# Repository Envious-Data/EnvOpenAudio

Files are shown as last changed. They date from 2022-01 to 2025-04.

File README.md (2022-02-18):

# EnvOpenAudio
 An open source headphone/PC speaker project utilizing the RP2040, UDA1334A and TPA2016

## Why
I like the idea of using the RP2040 for as many things as possible and since I made my own type-c version of the pico and my phone doesnt have a 3.5mm jack its a nice little bonus... I was also thinking I could use a Tiny2040 since its even smaller than a Pro Micro style board and also has all 4 Analogue GPIOs.

## I will need help
Im not a programmer, the most I can do is scripting in bash and python, that said I need someone who can do C stuff, although there is an example for using the Rpi pico as a I2S USB Sound Card it doesnt fully function, it functions enough to use for a while but mute doesnt work and eventually USB will die off for some reason.
https://github.com/raspberrypi/pico-playground/tree/master/apps/usb_sound_card

## Contributions
Feel free to make a PR if you want to provide your own 3d modeled housings for 3d printable speakers housings or headphone cups, Ill obviously be modeling my own but its always nice to see how people approach things.

## to do list (In no particular order)
- [x] Make Functional Concept
- [ ] Firmware
- [ ] PC Speaker Housinds
- [ ] Headphone cups and band
- [ ] Custom smaller PCBs of I2S Decoder and amp.
- [x] ~~Meow at wall for 3 hours~~

## Currently working on (as of last updating this)
- 3d printed housing for speakers, small desktop style pc speakers

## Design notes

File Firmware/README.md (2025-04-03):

# I NEED HELP!

So I am not able to do much more than basic scripting and I'd love if someone could help out by providing a simple firmware for the RP2040 for this project

This example does almost everything I need except it seems to exhibit some bugs so I will be using this to test and work on this project but yeah, need someone to do the firmware bits.
https://github.com/raspberrypi/pico-playground/tree/master/apps/usb_sound_card

## tl:dr:
need firmware for rp2040 to make it USB I2S DAC.

### bonus features
- a basic EQ to adjust sound a bit incase you use different kinds of speakers to me.

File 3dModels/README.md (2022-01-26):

# EnvOpenAudio

Everything for this project Ill intend to be 3d printed, I'd like for everything to be as accessible as possible as usual.

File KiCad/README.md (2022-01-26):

# EnvOpenAudio

These board schematics are from adafruit, Ive imported them into KiCad and swapped the footprints to KiCad version, I will be attempting to make these boards smaller as well as removing some stuff I wont use but the good thing about this is if you want you can build this project out of such parts you can buy from adafruit or equivilent shops minus the 3d printed housings.

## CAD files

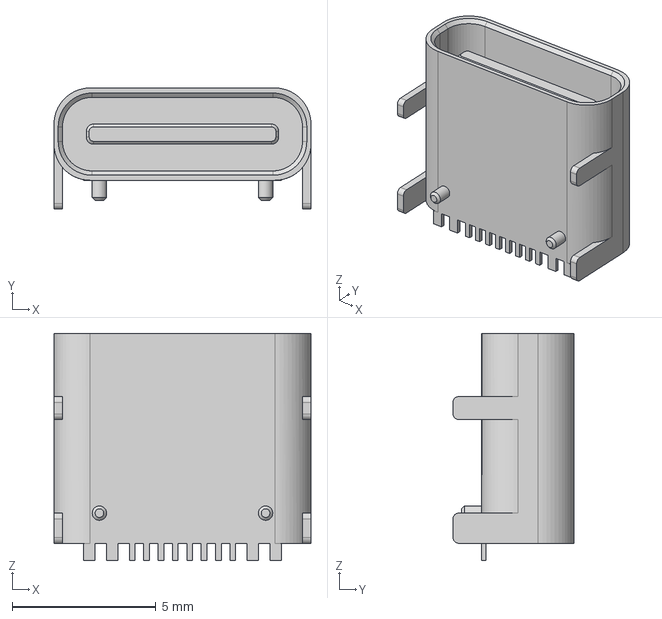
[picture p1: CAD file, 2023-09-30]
KiCad/EnvOpenAudio-RP2040/Resources/HRO TYPE-C-31-M-12.step
8.94 x 4.21 x 7.90 mm

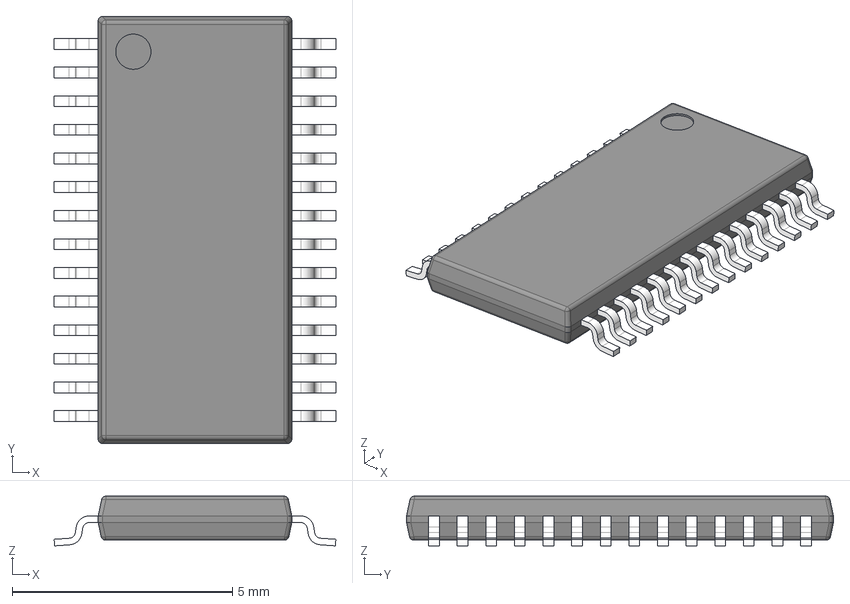
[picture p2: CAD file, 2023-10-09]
KiCad/EnvOpenAudio-RP2040/Resources/PCM3060PWR/PCM3060PWR.stp
6.40 x 9.70 x 1.13 mm
BODY-TSSOP
LEAD-TSSOP x 28
PIN1

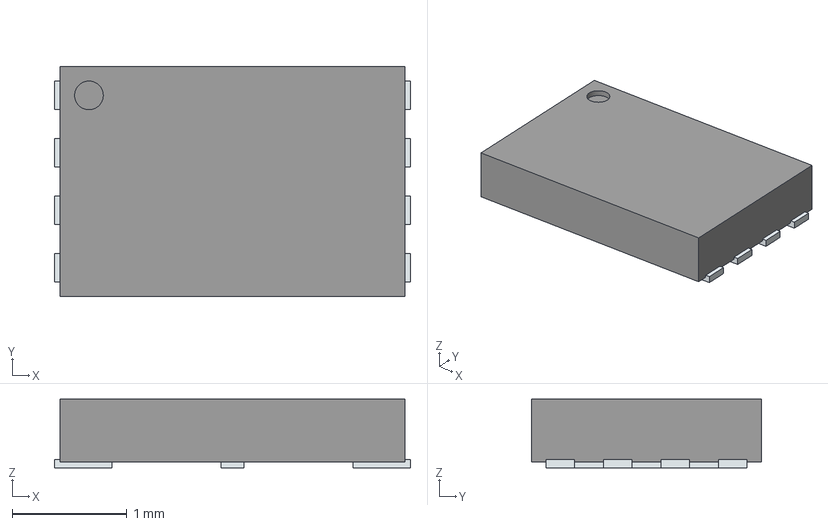
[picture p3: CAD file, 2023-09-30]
KiCad/EnvOpenAudio-RP2040/Resources/W25Q16JVUXIQ_TR.stp
3.10 x 2.00 x 0.6 mm
ThermalPin
PinsArrayLR

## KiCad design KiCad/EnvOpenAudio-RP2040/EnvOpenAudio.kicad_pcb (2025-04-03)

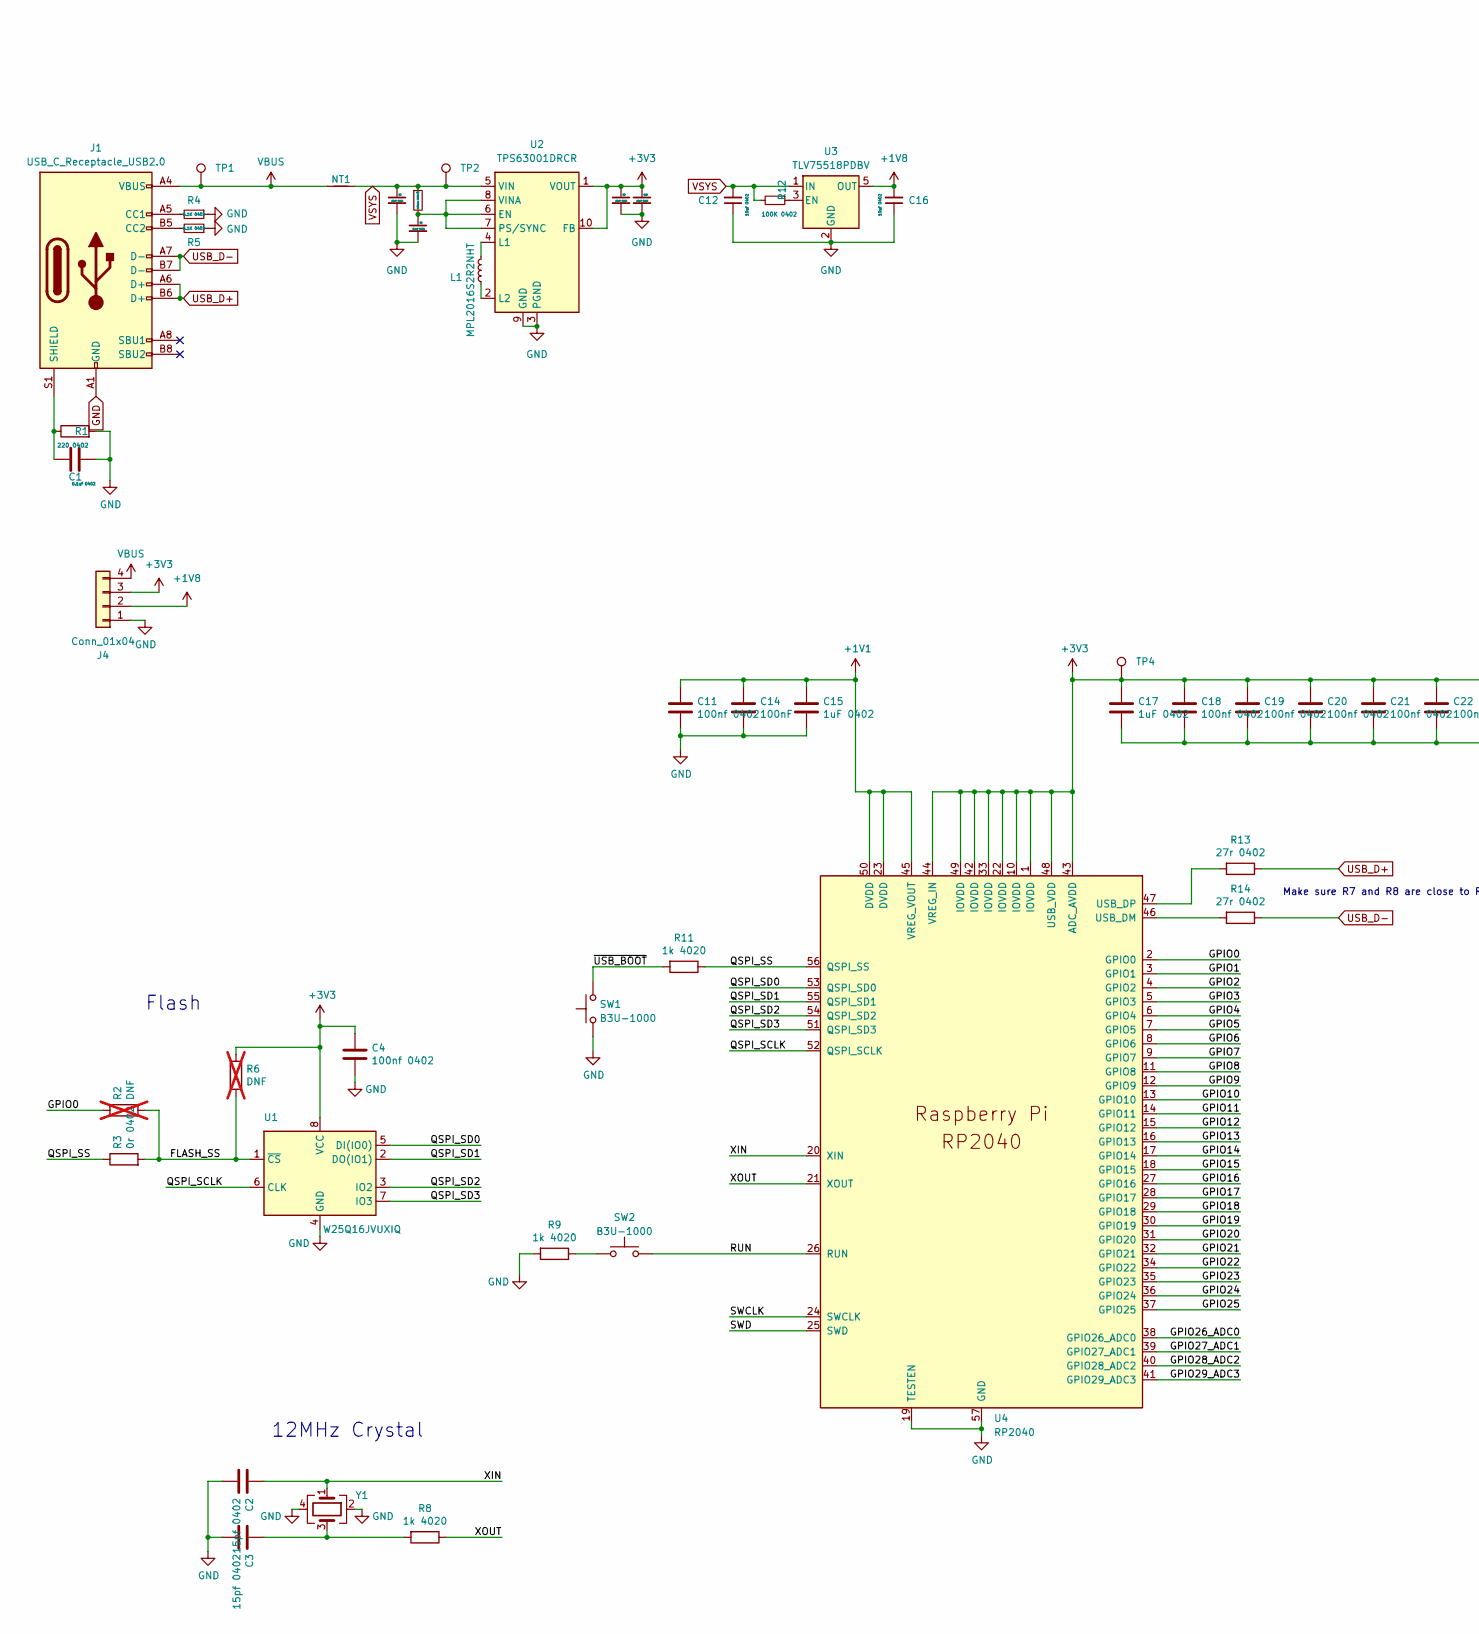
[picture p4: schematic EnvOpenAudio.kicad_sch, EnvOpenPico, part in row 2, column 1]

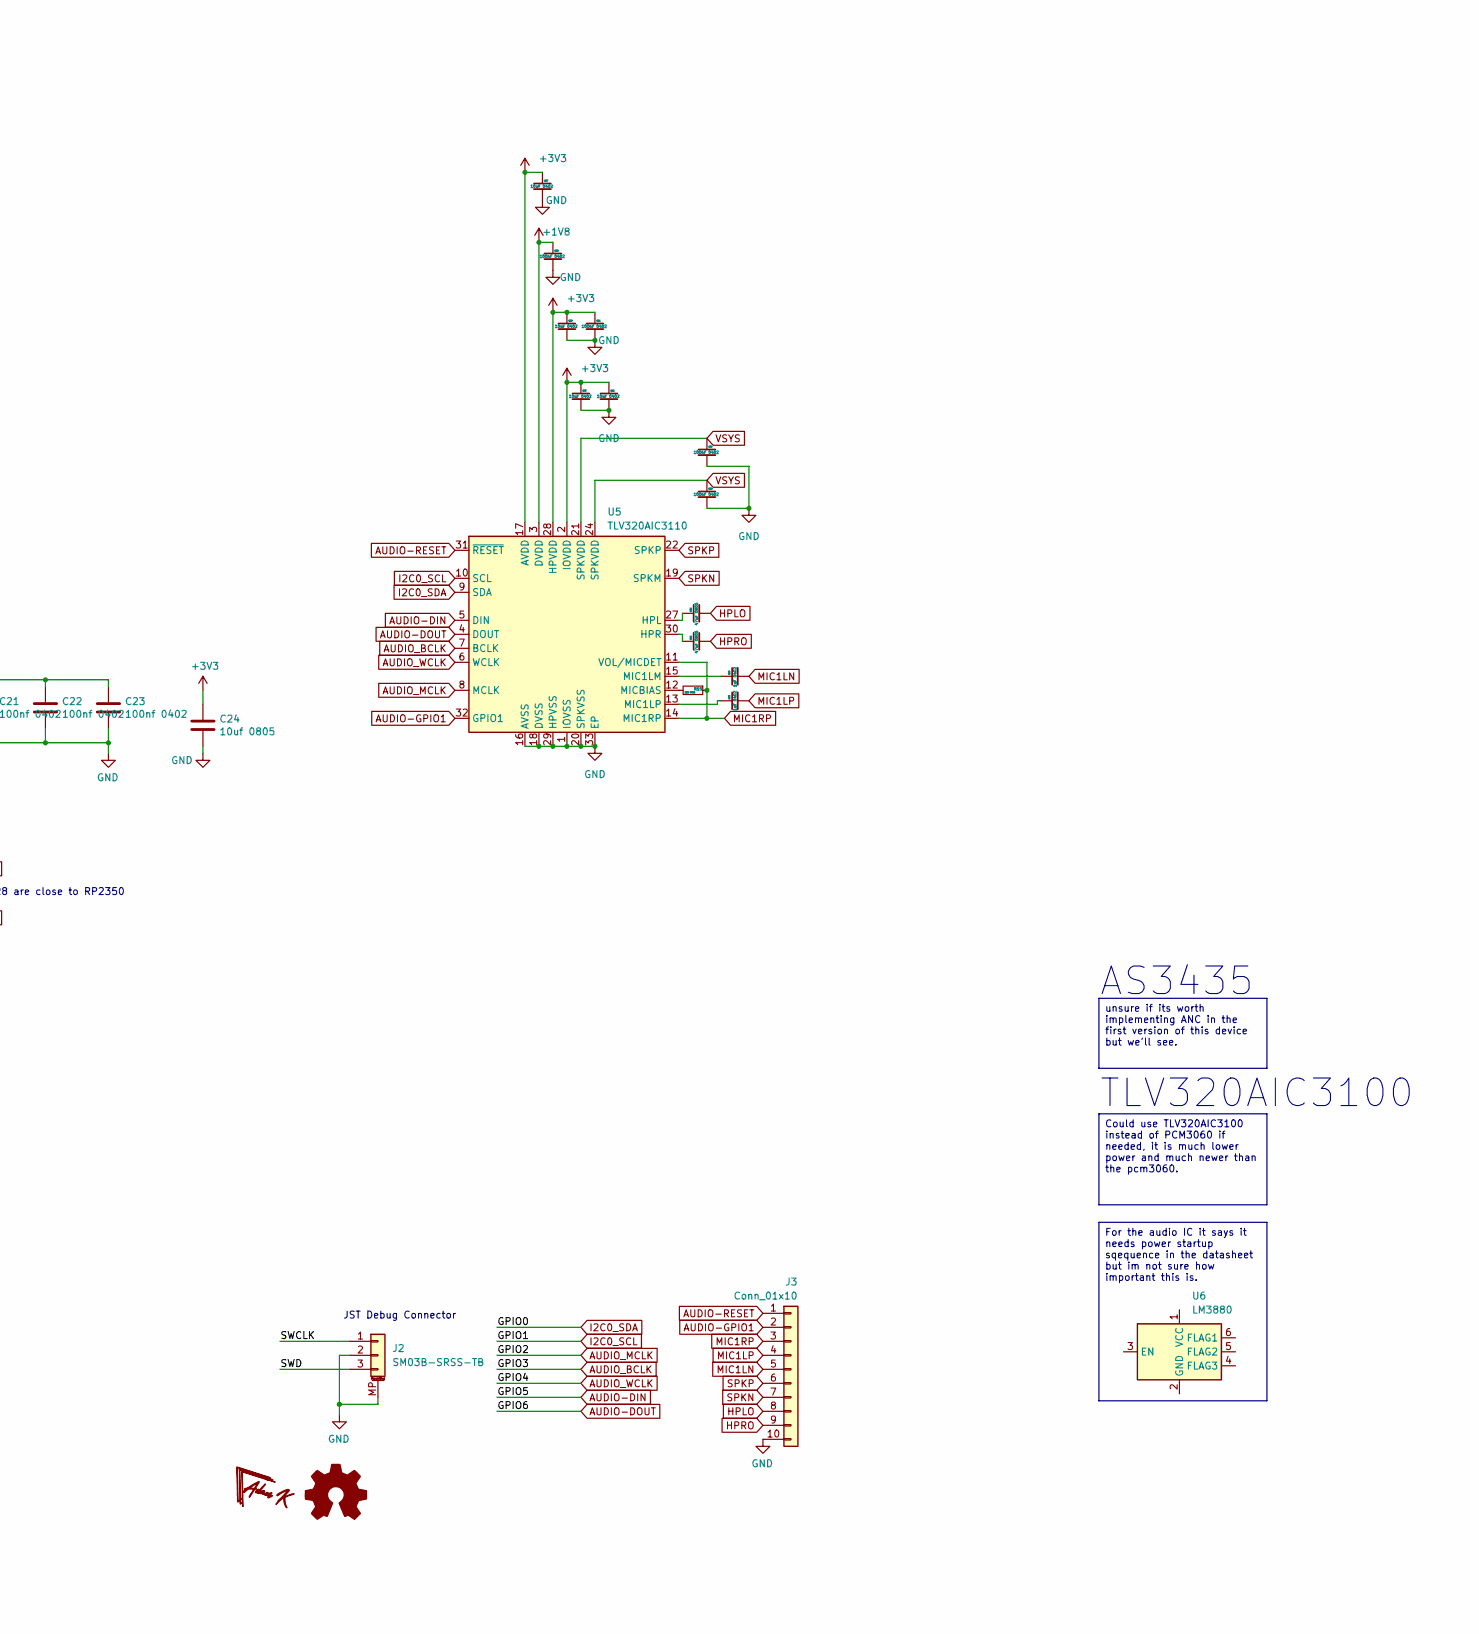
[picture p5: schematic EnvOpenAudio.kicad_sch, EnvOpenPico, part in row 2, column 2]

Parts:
C1: 0.1uf 0402; C_0402_1005Metric
C2, C3: 15pf 0402; C_0402_1005Metric
C4, C11, C18, C19, C20, C21, C22, C23: 100nf 0402; C_0402_1005Metric
C5, C9, C10, C27, C28, C30, C32: 10uF 0402; C_0402_1005Metric
C6: 0.1uF 0402; C_0402_1005Metric
C12, C16: 10uf 0402; C_0402_1005Metric
C14: 100nF; C_0402_1005Metric
C15, C17, C39, C40: 1uF 0402; C_0402_1005Metric
C24: 10uf 0805; C_0805_2012Metric
C29, C31, C37, C38: 100nF 0402; C_0402_1005Metric
C35, C36: 47uF 0805; C_0805_2012Metric
J1: USB_C_Receptacle_USB2.0; USB_C_Receptacle_HRO_TYPE-C-31-M-12
J2: SM03B-SRSS-TB; JST_SH_SM03B-SRSS-TB_1x03-1MP_P1.00mm_Horizontal
J3: Conn_01x10; PinHeader_2x05_P2.54mm_Vertical
J4: Conn_01x04; PinHeader_1x04_P2.54mm_Vertical
L1: MPL2016S2R2NHT; L_0805_2012Metric
NT1: NetTie_2; NetTie-2_SMD_Pad2.0mm
R1: 220 0402; R_0402_1005Metric
R2, R6: DNF; R_0402_1005Metric; not fitted
R3: 0r 0402; R_0402_1005Metric
R4, R5: 5.1K 0402; R_0402_1005Metric
R7: 100ohm 0402; R_0402_1005Metric
R8, R9, R11: 1k 4020; R_0402_1005Metric
R12: 100K 0402; R_0402_1005Metric
R13, R14: 27r 0402; R_0402_1005Metric
R15: 22K 0402; R_0402_1005Metric
SW1, SW2: B3U-1000; SW_SPST_B3U-1000P-B
TP1, TP2, TP3, TP4: TestPoint; TestPoint_Pad_D1.0mm
U1: W25Q16JVUXIQ; SON-8-1EP_3x2mm_P0.5mm_EP1.4x1.6mm
U2: TPS63001DRCR; Texas_DRC0010J_ThermalVias
U3: TLV75518PDBV; SOT-23-5
U4: RP2040; RP2040-QFN-56
U5: TLV320AIC3110; VQFN-32-1EP_5x5mm_P0.5mm_EP3.15x3.15mm_ThermalVias
U6: LM3880; SOT-23-6
Y1: 12Mhz 2520 18pF; Crystal_SMD_2520-4Pin_2.5x2.0mm

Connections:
+1V1: C11.1, C14.1, C15.1, U4.23 (DVDD), U4.45 (VREG_VOUT), U4.50 (DVDD)
+1V8: C16.2, C29.1, J4.2, U3.5 (OUT), U5.3 (DVDD)
+3V3: C4.1, C9.1, C10.1, C17.1, C18.1, C19.1, C20.1, C21.1, C22.1, C23.1, C24.1, C27.1, C28.1, C30.1, C31.1, C32.1, J4.3, R6.1, TP4.1, U1.8 (VCC), U2.1 (VOUT), U2.10 (FB), U4.1 (IOVDD), U4.10 (IOVDD), U4.22 (IOVDD), U4.33 (IOVDD), U4.42 (IOVDD), U4.43 (ADC_AVDD), U4.44 (VREG_IN), U4.48 (USB_VDD), U4.49 (IOVDD), U5.2 (IOVDD), U5.17 (AVDD), U5.28 (HPVDD)
/FLASH_SS: R2.2, R3.2, R6.2, U1.1 (~CS)
/GPIO7: U4.9 (GPIO7)
/GPIO8: U4.11 (GPIO8)
/GPIO9: U4.12 (GPIO9)
/GPIO10: U4.13 (GPIO10)
/GPIO11: U4.14 (GPIO11)
/GPIO12: U4.15 (GPIO12)
/GPIO13: U4.16 (GPIO13)
/GPIO14: U4.17 (GPIO14)
/GPIO15: U4.18 (GPIO15)
/GPIO16: U4.27 (GPIO16)
/GPIO17: U4.28 (GPIO17)
/GPIO18: U4.29 (GPIO18)
/GPIO19: U4.30 (GPIO19)
/GPIO20: U4.31 (GPIO20)
/GPIO21: U4.32 (GPIO21)
/GPIO22: U4.34 (GPIO22)
/GPIO23: U4.35 (GPIO23)
/GPIO24: U4.36 (GPIO24)
/GPIO25: U4.37 (GPIO25)
/GPIO26_ADC0: U4.38 (GPIO26_ADC0)
/GPIO27_ADC1: U4.39 (GPIO27_ADC1)
/GPIO28_ADC2: U4.40 (GPIO28_ADC2)
/GPIO29_ADC3: U4.41 (GPIO29_ADC3)
/QSPI_SCLK: U1.6 (CLK), U4.52 (QSPI_SCLK)
/QSPI_SD0: U1.5 (DI(IO0)), U4.53 (QSPI_SD0)
/QSPI_SD1: U1.2 (DO(IO1)), U4.55 (QSPI_SD1)
/QSPI_SD2: U1.3 (IO2), U4.54 (QSPI_SD2)
/QSPI_SD3: U1.7 (IO3), U4.51 (QSPI_SD3)
/QSPI_SS: R3.1, R11.1, U4.56 (QSPI_SS)
/RUN: SW2.2, U4.26 (RUN)
/SWCLK: J2.1, U4.24 (SWCLK)
/SWD: J2.3, U4.25 (SWD)
/XIN: C2.1, U4.20 (XIN), Y1.1
/XOUT: R8.1, U4.21 (XOUT)
/~USB_BOOT: R11.2, SW1.2
AUDIO-DIN: U4.7 (GPIO5), U5.5 (DIN)
AUDIO-DOUT: U4.8 (GPIO6), U5.4 (DOUT)
AUDIO-GPIO1: J3.2, U5.32 (GPIO1)
AUDIO-RESET: J3.1, U5.31 (~RESET)
AUDIO_BCLK: U4.5 (GPIO3), U5.7 (BCLK)
AUDIO_MCLK: U4.4 (GPIO2), U5.8 (MCLK)
AUDIO_WCLK: U4.6 (GPIO4), U5.6 (WCLK)
GND: C1.1, C2.2, C3.2, C4.2, C5.2, C6.2, C9.2, C10.2, C11.2, C12.1, C14.2, C15.2, C16.1, C17.2, C18.2, C19.2, C20.2, C21.2, C22.2, C23.2, C24.2, C27.2, C28.2, C29.2, C30.2, C31.2, C32.2, C37.2, C38.2, J1.A1 (GND), J1.A12 (GND), J1.B1 (GND), J1.B12 (GND), J2.2, J2.MP (MountPin), J3.10, J4.1, R1.2, R4.1, R5.1, R9.2, SW1.1, U1.4 (GND), U2.3 (PGND), U2.9 (GND), U2.11 (PGND), U3.2 (GND), U4.19 (TESTEN), U4.57 (GND), U5.1 (IOVSS), U5.16 (AVSS), U5.18 (DVSS), U5.20 (SPKVSS), U5.25 (SPKVSS), U5.29 (HPVSS), U5.33 (EP), Y1.2, Y1.4
HPLO: C35.2, J3.8
HPRO: C36.2, J3.9
I2C0_SCL: U4.3 (GPIO1), U5.10 (SCL)
I2C0_SDA: R2.1, U4.2 (GPIO0), U5.9 (SDA)
MIC1LN: C39.2, J3.5
MIC1LP: C40.2, J3.4
MIC1RP: J3.3, R15.1, U5.11 (VOL/MICDET), U5.14 (MIC1RP)
unnamed: C3.1, R8.2, Y1.3
unnamed: J1.A5 (CC1), R4.2
unnamed: J1.B5 (CC2), R5.2
unnamed: C1.2, J1.S1 (SHIELD), R1.1
unnamed: R9.1, SW2.1
unnamed: C6.1, R7.2, U2.6 (EN), U2.7 (PS/SYNC), U2.8 (VINA)
unnamed: L1.1, U2.4 (L1)
unnamed: L1.2, U2.2 (L2)
unnamed: R12.1, U3.3 (EN)
unnamed: R14.2, U4.46 (USB_DM)
unnamed: R13.2, U4.47 (USB_DP)
unnamed: C35.1, U5.27 (HPL)
unnamed: C36.1, U5.30 (HPR)
unnamed: C39.1, U5.15 (MIC1LM)
unnamed: C40.1, U5.13 (MIC1LP)
unnamed: R15.2, U5.12 (MICBIAS)
SPKN: J3.7, U5.19 (SPKM), U5.23 (SPKM)
SPKP: J3.6, U5.22 (SPKP), U5.26 (SPKP)
USB_D+: J1.A6 (D+), J1.B6 (D+), R13.1
USB_D-: J1.A7 (D-), J1.B7 (D-), R14.1
VBUS: J1.A4 (VBUS), J1.A9 (VBUS), J1.B4 (VBUS), J1.B9 (VBUS), J4.4, NT1.1, TP1.1
VSYS: C5.1, C12.2, C37.1, C38.1, NT1.2, R7.1, R12.2, TP2.1, U2.5 (VIN), U3.1 (IN), U5.21 (SPKVDD), U5.24 (SPKVDD)

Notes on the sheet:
Could use TLV320AIC3100 instead of PCM3060 if needed, it is much lower power and much newer than the pcm3060.
For the audio IC it says it needs power startup sqequence in the datasheet but im not sure how important this is.
unsure if its worth implementing ANC in the first version of this device but we'll see.
AS3435
Make sure R7 and R8 are close to RP2350
JST Debug Connector
TLV320AIC3100
12MHz Crystal
Flash

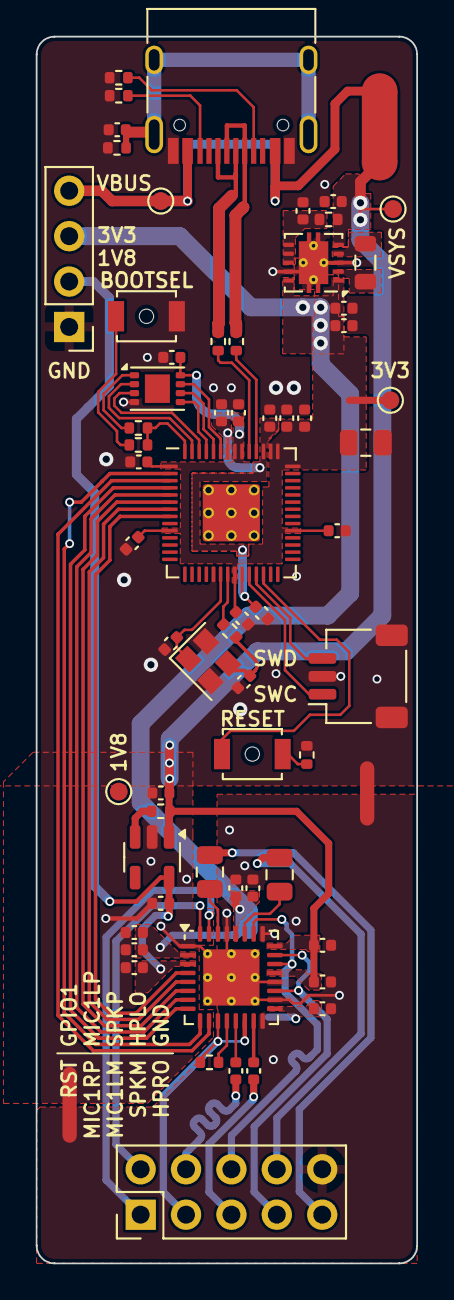
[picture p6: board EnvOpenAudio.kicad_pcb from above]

Board: 2 copper layers, 21.3 x 68.7 mm, 63 parts (0 on the bottom side), 53 nets.

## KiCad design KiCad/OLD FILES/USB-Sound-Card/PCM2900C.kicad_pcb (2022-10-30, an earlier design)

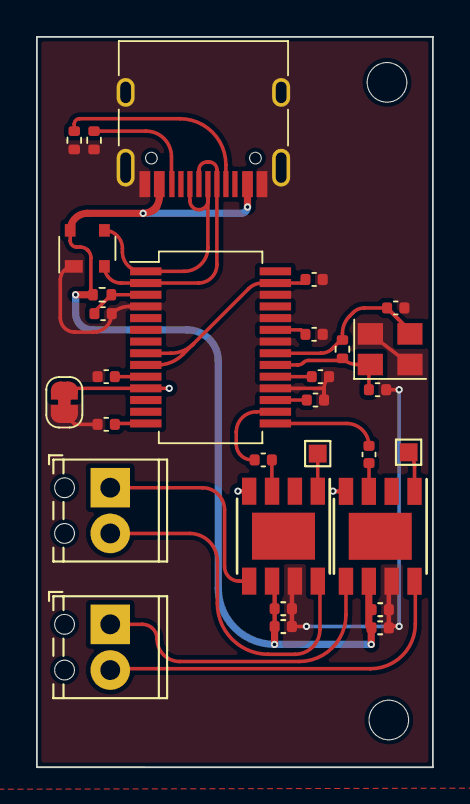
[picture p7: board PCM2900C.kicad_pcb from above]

Board: 2 copper layers, 22.0 x 40.6 mm, 33 parts (1 on the bottom side), 26 nets.

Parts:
C1, C3, C6, C7, C8: 10µF; C_0402_1005Metric
C2, C4, C9, C10, C11, C12, C13, C14: 1µF; C_0402_1005Metric
C15, C16: 22pF; C_0402_1005Metric
D1: PRTR5V0U2X; SOT-143
H1, H2: MountingHole; MountingHole_2.2mm_M2
J1, J2: Conn_01x02; TerminalBlock_Phoenix_MPT-0,5-2-2.54_1x02_P2.54mm_Horizontal
J3, J4: Conn_01x01; TestPoint_Pad_1.0x1.0mm
J101: USB_C_Receptacle_USB2.0; USB_C_Receptacle_HRO_TYPE-C-31-M-12
R1: 1M; R_0402_1005Metric
R2: 2R2; R_0402_1005Metric
R101, R102: 5.1K 0805; R_0402_1005Metric
STAR2: SolderJumper_2_Bridged; SolderJumper-2_P1.3mm_Bridged_RoundedPad1.0x1.5mm
U1, U2: PAM8302AAD; Diodes_SO-8EP
U101: PCM2900C; SSOP-28_5.3x10.2mm_P0.65mm
Y1: 12MHz 18pF; Crystal_SMD_3225-4Pin_3.2x2.5mm
kibuzzard-6354995E: G***; kibuzzard-6354995E

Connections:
/L-USB-In: C14.2, U2.3 (IN+)
/R-USB-In: C13.2, U1.3 (IN+)
AGNDC: STAR2.2 (B), U1.4 (IN-), U2.4 (IN-), U101.11 (AGNDC)
AGNDP: C1.2, C2.1, C3.2, C4.1, C6.2, C7.2, C8.2, C9.2, C10.2, C11.2, C12.2, C15.2, C16.2, D1.1 (GND), J101.A1 (GND), J101.A12 (GND), J101.B1 (GND), J101.B12 (GND), J101.S1 (SHIELD), R101.2, R102.2, STAR2.1 (A), U1.7 (GND), U2.7 (GND), U101.4 (DGNDU), U101.18 (AGNDP), U101.22 (AGNDX), U101.24 (DIN), U101.26 (DGND), Y1.2, Y1.4
unnamed: C6.1, R2.2, U101.3 (VBUS)
unnamed: C9.1, U101.8 (SEL0), U101.9 (SEL1), U101.27 (VDDI)
unnamed: C10.1, U101.23 (VCCXI)
unnamed: C11.1, U101.17 (VCCP1I)
unnamed: C12.1, U101.19 (VCCP2I)
unnamed: C15.1, R1.2, U101.20 (XTO), Y1.1
unnamed: C16.1, R1.1, U101.21 (XTI), Y1.3
unnamed: J1.1, U1.5 (OUT+)
unnamed: J1.2, U1.8 (OUT-)
unnamed: J2.1, U2.5 (OUT+)
unnamed: J2.2, U2.8 (OUT-)
unnamed: J3.1, U1.1 (~SD)
unnamed: J4.1, U2.1 (~SD)
unnamed: J101.A5 (CC1), R101.1
unnamed: J101.B5 (CC2), R102.1
USB D+: D1.3 (I/O2), J101.A6 (D+), J101.B6 (D+), U101.1 (D+)
USB D-: D1.2 (I/O1), J101.A7 (D-), J101.B7 (D-), U101.2 (D-)
VBUS: C1.1, C2.2, C3.1, C4.2, D1.4 (VCC), J101.A4 (VBUS), J101.A9 (VBUS), J101.B4 (VBUS), J101.B9 (VBUS), R2.1, U1.6 (VDD), U2.6 (VDD)
VCCCI: C7.1, U101.10 (VCCCI)
VCOM: C8.1, U101.14 (VCOM)
VOUTL: C13.1, U101.16 (VOUTL)
VOUTR: C14.1, U101.15 (VOUTR)

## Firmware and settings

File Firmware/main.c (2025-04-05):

#include <stdlib.h>
#include <stdio.h>
#include <string.h>
#include "pico/stdlib.h"
#include "pico/audio_i2s.h"
#include "tusb.h"
#include "usb_descriptors.h"

#include <pico/stdio.h>

// I2S Configuration
#define I2S_BCK_PIN   5
#define I2S_WS_PIN    3
#define I2S_DATA_PIN  4

int main() {
    stdio_init_all();
    printf("\n || Starting USB I2S DAC|| \n");

    // Initialize TinyUSB
    tusb_init();
	printf("tud_init() called");


	printf("tud_task() loop called\n");
    while (true) {
        tud_task(); // TinyUSB device task
    }

    return 0;
}

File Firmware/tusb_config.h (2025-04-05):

/*
 * The MIT License (MIT)
 *
 * Copyright (c) 2020 Ha Thach (tinyusb.org)
 * Copyright (c) 2020 Jerzy Kasenberg
 *
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
 */

#ifndef _TUSB_CONFIG_H_
#define _TUSB_CONFIG_H_

#ifdef __cplusplus
extern "C" {
#endif

#include "usb_descriptors.h"

//--------------------------------------------------------------------+
// Board Specific Configuration
//--------------------------------------------------------------------+

// RHPort number used for device can be defined by board.mk, default to port 0
#ifndef BOARD_TUD_RHPORT
#define BOARD_TUD_RHPORT      0
#endif

// RHPort max operational speed can defined by board.mk
#ifndef BOARD_TUD_MAX_SPEED
#define BOARD_TUD_MAX_SPEED   OPT_MODE_DEFAULT_SPEED
#endif

//--------------------------------------------------------------------
// Common Configuration
//--------------------------------------------------------------------

// defined by compiler flags for flexibility
#ifndef CFG_TUSB_MCU
#error CFG_TUSB_MCU must be defined
#endif

#ifndef CFG_TUSB_OS
#define CFG_TUSB_OS           OPT_OS_NONE
#endif

#ifndef CFG_TUSB_DEBUG
#define CFG_TUSB_DEBUG        0
#endif

// Enable Device stack
#define CFG_TUD_ENABLED       1

// Default is max speed that hardware controller could support with on-chip PHY
#define CFG_TUD_MAX_SPEED     BOARD_TUD_MAX_SPEED

/* USB DMA on some MCUs can only access a specific SRAM region with restriction on alignment.
 * Tinyusb use follows macros to declare transferring memory so that they can be put
 * into those specific section.
 * e.g
 * - CFG_TUSB_MEM SECTION : __attribute__ (( section(".usb_ram") ))
 * - CFG_TUSB_MEM_ALIGN   : __attribute__ ((aligned(4)))
 */
#ifndef CFG_TUSB_MEM_SECTION
#define CFG_TUSB_MEM_SECTION
#endif

#ifndef CFG_TUSB_MEM_ALIGN
#define CFG_TUSB_MEM_ALIGN        __attribute__ ((aligned(4)))
#endif

//--------------------------------------------------------------------
// DEVICE CONFIGURATION
//--------------------------------------------------------------------

#ifndef CFG_TUD_ENDPOINT0_SIZE
#define CFG_TUD_ENDPOINT0_SIZE    64
#endif

#define CFG_TUSB_RHPORT0_MODE OPT_MODE_DEVICE 
#define CFG_TUSB_RHPORT1_MODE OPT_MODE_NONE 

//------------- CLASS -------------//
#define CFG_TUD_CDC               1
#define CFG_TUD_MSC               0
#define CFG_TUD_HID               0
#define CFG_TUD_MIDI              0
#define CFG_TUD_AUDIO             1
#define CFG_TUD_VENDOR            1

//------------- CLASS -------------//
// buffer for USB debugging
//
#define CFG_TUD_CDC_RX_BUFSIZE 64
#define CFG_TUD_CDC_TX_BUFSIZE 64
#define CFG_TUD_CDC_EP_BUFSIZE 64

//--------------------------------------------------------------------
// AUDIO CLASS DRIVER CONFIGURATION
//--------------------------------------------------------------------

// Allow volume controlled by on-baord button
#define CFG_TUD_AUDIO_ENABLE_INTERRUPT_EP                            1

#define CFG_TUD_AUDIO_FUNC_1_DESC_LEN                                TUD_AUDIO_HEADSET_STEREO_DESC_LEN

// How many formats are used, need to adjust USB descriptor if changed
#define CFG_TUD_AUDIO_FUNC_1_N_FORMATS                               2

// Audio format type I specifications
/* 24bit/48kHz is the best quality for headset or 24bit/96kHz for 2ch speaker,
   high-speed is needed beyond this */
#define CFG_TUD_AUDIO_FUNC_1_MAX_SAMPLE_RATE                         48000
#define CFG_TUD_AUDIO_FUNC_1_N_CHANNELS_TX                           0
#define CFG_TUD_AUDIO_FUNC_1_N_CHANNELS_RX                           2

// 16bit in 16bit slots
#define CFG_TUD_AUDIO_FUNC_1_FORMAT_1_N_BYTES_PER_SAMPLE_TX          2
#define CFG_TUD_AUDIO_FUNC_1_FORMAT_1_RESOLUTION_TX                  16
#define CFG_TUD_AUDIO_FUNC_1_FORMAT_1_N_BYTES_PER_SAMPLE_RX          2
#define CFG_TUD_AUDIO_FUNC_1_FORMAT_1_RESOLUTION_RX                  16

#if defined(__RX__)
// 8bit in 8bit slots
#define CFG_TUD_AUDIO_FUNC_1_FORMAT_2_N_BYTES_PER_SAMPLE_TX          1
#define CFG_TUD_AUDIO_FUNC_1_FORMAT_2_RESOLUTION_TX                  8
#define CFG_TUD_AUDIO_FUNC_1_FORMAT_2_N_BYTES_PER_SAMPLE_RX          1
#define CFG_TUD_AUDIO_FUNC_1_FORMAT_2_RESOLUTION_RX                  8
#else
// 24bit in 32bit slots
#define CFG_TUD_AUDIO_FUNC_1_FORMAT_2_N_BYTES_PER_SAMPLE_TX          4
#define CFG_TUD_AUDIO_FUNC_1_FORMAT_2_RESOLUTION_TX                  24
#define CFG_TUD_AUDIO_FUNC_1_FORMAT_2_N_BYTES_PER_SAMPLE_RX          4
#define CFG_TUD_AUDIO_FUNC_1_FORMAT_2_RESOLUTION_RX                  24
#endif

// EP and buffer size - for isochronous EP´s, the buffer and EP size are equal (different sizes would not make sense)
#define CFG_TUD_AUDIO_ENABLE_EP_IN                1
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

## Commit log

2022-01-26 added files and more content to readmes
    [TPA2016D2.kicad_pcb, TPA2016D2.kicad_sch, UDA1334.kicad_pcb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]
2022-01-26 started swapping symbols from eagle import to KiCad
    [UDA1334.kicad_sch]
2022-02-18 converted TPA2016D2 schematic to kicad symbols
    [TPA2016D2.kicad_sch]
2022-02-19 started work on combining the two schematics
    [TPA2016+UDA1334.kicad_pcb, TPA2016+UDA1334.kicad_sch]
2022-03-24 modified schematic symbol to be a bit nicer
    [TPA2016D2.kicad_sch]
2022-06-10 actually combined both board schematics, need to do more tho
    [TPA2016+UDA1334.kicad_sch, TPA2016D2.kicad_pcb, TPA2016D2.kicad_sch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]
2022-06-21 more bits
    [PCM2900C.kicad_pcb, PCM2900C.kicad_sch]
2022-06-25 hastily slapped together pcb
    [PCM2900C.kicad_pcb, PCM2900C.kicad_sch]
2022-06-26 added some amps, may change
    [PCM2900C.kicad_sch]
2022-10-30 some general board design progress and rearrangement, need to re-do bits of the board still
    [PCM2900C.kicad_pcb, PCM2900C.kicad_sch]
2023-09-30 prepared repo for new work
    [PCM2900C.kicad_pcb, PCM2900C.kicad_sch, TPA2016+UDA1334.kicad_pcb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]
2023-09-30 added 2040 base schematic and board
    [EnvOpenAudio.kicad_pcb, EnvOpenAudio.kicad_sch]
2023-09-30 started work on RP2040 board
    [EnvOpenAudio.kicad_pcb, EnvOpenAudio.kicad_sch]
2023-09-30 added some 3d models
    [EnvOpenAudio.kicad_pcb, HRO TYPE-C-31-M-12.step, W25Q16JVUXIQ_TR.stp]
2023-10-09 added PCM3060, picked due to low cost.
    [EnvOpenAudio.kicad_sch, PCM3060PWR.stp]
2023-11-29 added a couple notes on ANC and alternative IC.
    [EnvOpenAudio.kicad_sch]
2023-12-08 added some stuff, dont remember lol
    [EnvOpenAudio.kicad_sch]
2024-06-03 wired up audio IC
    [EnvOpenAudio.kicad_pcb, EnvOpenAudio.kicad_sch]
2024-06-05 wired up majority of PCB, added headers and labels.
    [EnvOpenAudio.kicad_pcb, EnvOpenAudio.kicad_sch]
2024-09-11 Swapped RP2040 for RP2350A for FPU, re-did board and schematic, added labels back and naming, Github link
    [EnvOpenAudio.kicad_pcb, EnvOpenAudio.kicad_sch]
2024-09-12 added test pads, swapped inductors for smaller models
    [EnvOpenAudio.kicad_pcb, EnvOpenAudio.kicad_sch]
2024-09-15 changed some component sizes, values ,added seperate analogue ground with small stitching to digital ground.
    [EnvOpenAudio.kicad_pcb, EnvOpenAudio.kicad_sch]
2025-01-16 Seperated into RP2040 and RP2350 variants
    [EnvOpenAudio.kicad_pcb, EnvOpenAudio.kicad_sch, HRO TYPE-C-31-M-12.step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]
2025-04-03 few small changes, still need help with firmware.
    [EnvOpenAudio.kicad_pcb, EnvOpenAudio.kicad_sch]
2025-04-03 attempt to implement i2s and tinyusb but it does not work.
    [main.c, tusb_config.h]
2025-04-05 found out pico2 was faulty, switched to pico
